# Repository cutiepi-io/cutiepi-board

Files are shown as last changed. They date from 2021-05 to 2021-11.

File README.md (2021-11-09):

# CutiePi board V2.3

This repository provides a custom carrier board designed for the open source CutiePi tablet project, to make use of the Raspberry Pi Compute Module 4.

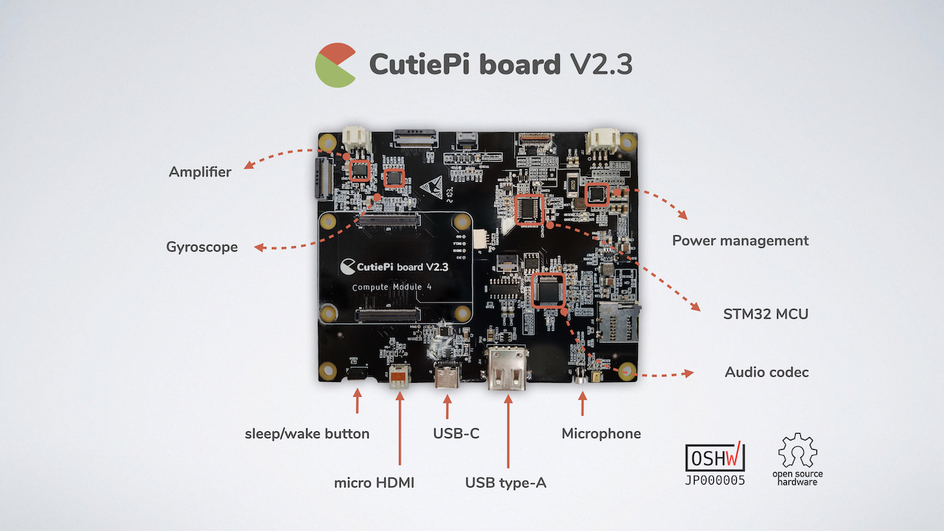
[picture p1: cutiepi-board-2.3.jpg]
 

## Contents

- Cadence OrCAD Schematic [CutiePi_V2.3-20210409.DSN](CutiePi_V2.3-20210409.DSN)
- Cadence OrCAD/Allegro PCB file [CutiePi_V2_3.brd](CutiePi_V2_3_TapeOut/CutiePi_V2_3_PCB/CutiePi_V2_3.brd)
- Bill of Materials [CutiePi_V2.3_BOM-20210802.xlsx](CutiePi_V2.3_BOM-20210802.xlsx)
- PDF of schematic [CutiePi_V2.3_schematic-20210414.pdf](CutiePi_V2.3_schematic-20210414.pdf)

## Copyright and License
Copyright (c) 2021 Zhang "Iron Pillar" Hogan. All rights reserved.

Part of CutiePi board's design is based on Pi Foundation's 
[Compute Module 4 IO Board](https://github.com/raspberrypi/documentation/blob/master/hardware/computemodule/designfiles.md), and we are releasing it under the same [modified BSD license](LICENSE.txt). 

All documentation is licensed under a Creative Commons BY-SA 4.0 international license.

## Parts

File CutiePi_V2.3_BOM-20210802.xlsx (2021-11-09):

No. | Qt | Ref | Value | Package | 备注
1 | 5 | C2,C20,C2484,C2487,C2505 | 47uF/6.3V | C1206
2 | 17 | C17,C383,C384,C385,C2477,C2492,C2493,C2495,C2502,C2503,C2509,C2511,C2512,C2521,C2524,C2525,C2526 | 100nF | C0402
3 | 8 | C24,C86,C2478,C2481,C2501,C2504,C2513,C2520 | 4.7uF/16V | C0603
4 | 4 | C68,C73,C80,C81 | 0.1uF/50V | C0603
5 | 1 | C69 | 1.0uF/25V | C0805
6 | 2 | C74,C78 | 0.22uF/50V | C0805
7 | 2 | C76,C85 | 4.7uF/50V | C1210
8 | 1 | C82 | 1000pF/50V | C0603
9 | 1 | C87 | 0.39uF/16V | C0603
10 | 1 | C386 | 2.2nF | C0402
11 | 4 | C2474,C2480,C2514,C2515 | 1uF/10V | C0402
12 | 2 | C2475,C2476 | 12pF | C0402
13 | 2 | C2479,C2523 | 10nF | C0402
14 | 2 | C2483,C2508 | 2.2uF | C0402
15 | 8 | C2485,C2486,C2488,C2489,C2490,C2491,C2496,C2497 | 10uF/16V | C0805
16 | 3 | C2507,C2516,C2518 | 10uF/16V | C0603
17 | 4 | C2510,C2517,C2519,C2522 | 47pF | C0603
18 | 2 | D1,D23 | RED | LED0603
19 | 1 | D10 | SS14-M3/61T | DO-214AC
20 | 4 | D11,D12,D13,D14 | ESDLIN1524BJ | SOD323
21 | 2 | D17,D18 | BAT54HT1 | DIO-SOD323
22 | 4 | D19,D20,D21,D22 | GREEN | LED0603
23 | 7 | FB2,FB7,FB8,FB9,FB10,FB12,FB13 | BLM18PG121SH1 | SL0603
24 | 1 | F1 | 6V/2A | 1206
25 | 1 | F2 | 6V/0.5A | 1206
26 | 1 | J2 | Type C-16 | TYPEC_6446_116FH1301 | https://detail.tmall.com/item.htm?id=609627153021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
27 | 1 | J7 | SH1.0-4 | SH1_0_4 | https://detail.tmall.com/item.htm?id=548124065090&rn=de18d88c60677f1377dbfd09a6918efa&abbucket=17
28 | 1 | J9 | SH1.0-2 | SH1_0_2 | https://detail.tmall.com/item.htm?pos=2&acm=03054.1003.1.2768562&id=548071500587&skuId=3324081389692
29 | 2 | J11,J26 | FH52-22S-0.5SH | CONFPC22_05MM_FH52_a
30 | 1 | J13 | 467651001 | Micro_HDMI
31 | 1 | J14 | USB-A | USB_AM
32 | 1 | J16 | 473521001_sd | MOLEX_473521001
33 | 2 | J17,J28 | FH52-6S-0.5SH | confpc6_05mm_FH52
34 | 1 | J21 | FH26W-31S-0.3SHW | confpc31_03mm_FH26w
35 | 1 | J23 | PH2.0-3_NC | PH2_0_3
36 | 2 | J24,J25 | DF40C-100DS-0.4V | FCI_10033853_CM
37 | 1 | J27 | MIC4.5 | MIC_4_5 | https://detail.tmall.com/item.htm?id=524833449267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
38 | 1 | L5 | 10uH/20% | SHC0402
39 | 1 | L634 | 1.5uF | SHC0402
40 | 5 | Q3,Q4,Q5,Q6,Q7 | DMG1012T | SOT50P160X90-3N
41 | 8 | R3,R3060,R3087,R3095,R3097,R3100,R3178,R3179 | 2.49K | R0402
42 | 11 | R15,R87,R118,R3040,R3061,R3101,R3167,R3173,R3176,R3180,R3182 | 10K_NC | R0402
43 | 9 | R16,R17,R114,R115,R124,R3165,R3166,R3168,R3169 | 4.7K | R0402
44 | 33 | R18,R117,R272,R368,R371,R3039,R3043,R3044,R3054,R3057,R3059,R3062,R3066,R3088,R3094,R3096,R3099,R3102,R3104,R3105,R3108,R3132,R3145,R3149,R3160,R3163,R3164,R3177,R3181,R3183,R3186,R3189,R3196 | 10K | R0402
45 | 25 | R42,R43,R88,R89,R120,R121,R127,R370,R373,R3041,R3042,R3058,R3098,R3153,R3156,R3157,R3158,R3172,R3174,R3175,R3193,R3194,R3195,R3197,R3200 | 0 | R0402
46 | 4 | R90,R91,R3184,R3188 | 3.3 | R0603
47 | 9 | R122,R123,R3154,R3155,R3161,R3162,R3198,R3199,R3201 | 0_NC | R0402
48 | 2 | R125,R126 | 20K | R0402
49 | 2 | R3049,R3103 | 30.1K | R0402
50 | 3 | R3051,R3053,R3065 | 52.3K | R0402
51 | 4 | R3052,R3064,R3091,R3093 | 15K | R0402
52 | 1 | R3063 | 3.3_NC | R0603
53 | 1 | R3086 | 31.6K | R0402
54 | 1 | R3089 | 20m/1W | R2512
55 | 4 | R3090,R3133,R3134 | 5.1K | R0402
56 | 1 | R3106 | 82.5K | R0402
57 | 1 | R3107 | 39.2K | R0402
58 | 1 | R3137 | 36.5K | R0402
59 | 6 | R3138,R3139,R3140,R3141,R3142,R3143 | 22 | R0402
60 | 3 | R3185,R3187,R3190 | 2.2K | R0402
61 | 2 | R3191,R3192 | 8.2K | R0402
62 | 1 | SW2 | TC-0143 | Button
63 | 39 | TP28,TP29,TP30,TP33,TP41,TP43,TP44,TP45,TP46,TP47,TP52,TP57,TP58,TP59,TP60,TP61,TP62,TP63,TP64,TP65,TP77,TP78,TP79,TP80,TP81,TP83,TP84,TP89,TP90,TP91,TP92,TP93,TP94,TP95,TP97,TP98,TP99,TP100,TP101 | TEST POINT | testpoint_39mil
64 | 1 | U3 | HS100B | QFN48_05MM_0707MMLTS
65 | 2 | U5,U601 | IP4234CZ6 | TSOP6
66 | 1 | U6 | TPS61165DBV | SOT23_6B
67 | 1 | U12 | LM4871MX | SOIC8_1D27MM
68 | 1 | U18 | STM32F030F4P6 | TSSOP20_0D65MM
69 | 1 | U57 | MPU6050 | QFN24_05MM_0404MML
70 | 1 | U60 | TPS73601DBVR | SOT23_5
71 | 1 | U501 | SPU0410HR5H_NC | lga5_cav_4p1x3p1mm
72 | 1 | U580 | AT93C46 | SOIC8
73 | 1 | U597 | MP2636GR | QFN-30
74 | 1 | U600 | HS8836A | SOP16_1P27_HS8836A
75 | 1 | U602 | FSUSB42MUX | sop10_20_120a
76 | 1 | Y2 | 25M_NC | XTAL_3225_25M_A
77 | 1 | R3092 | 3K | R0402
78 | 1 | Cxxx | 220uF/10V | 引脚，手工焊接！
79 | 1 |  |  | U602 1脚跟2脚短接
 |  |  |  | 注意PCB板厚1.2mm！！！

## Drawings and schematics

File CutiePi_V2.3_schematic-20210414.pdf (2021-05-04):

DISPLAY | CAMMERA 1 | CAMMERA 0

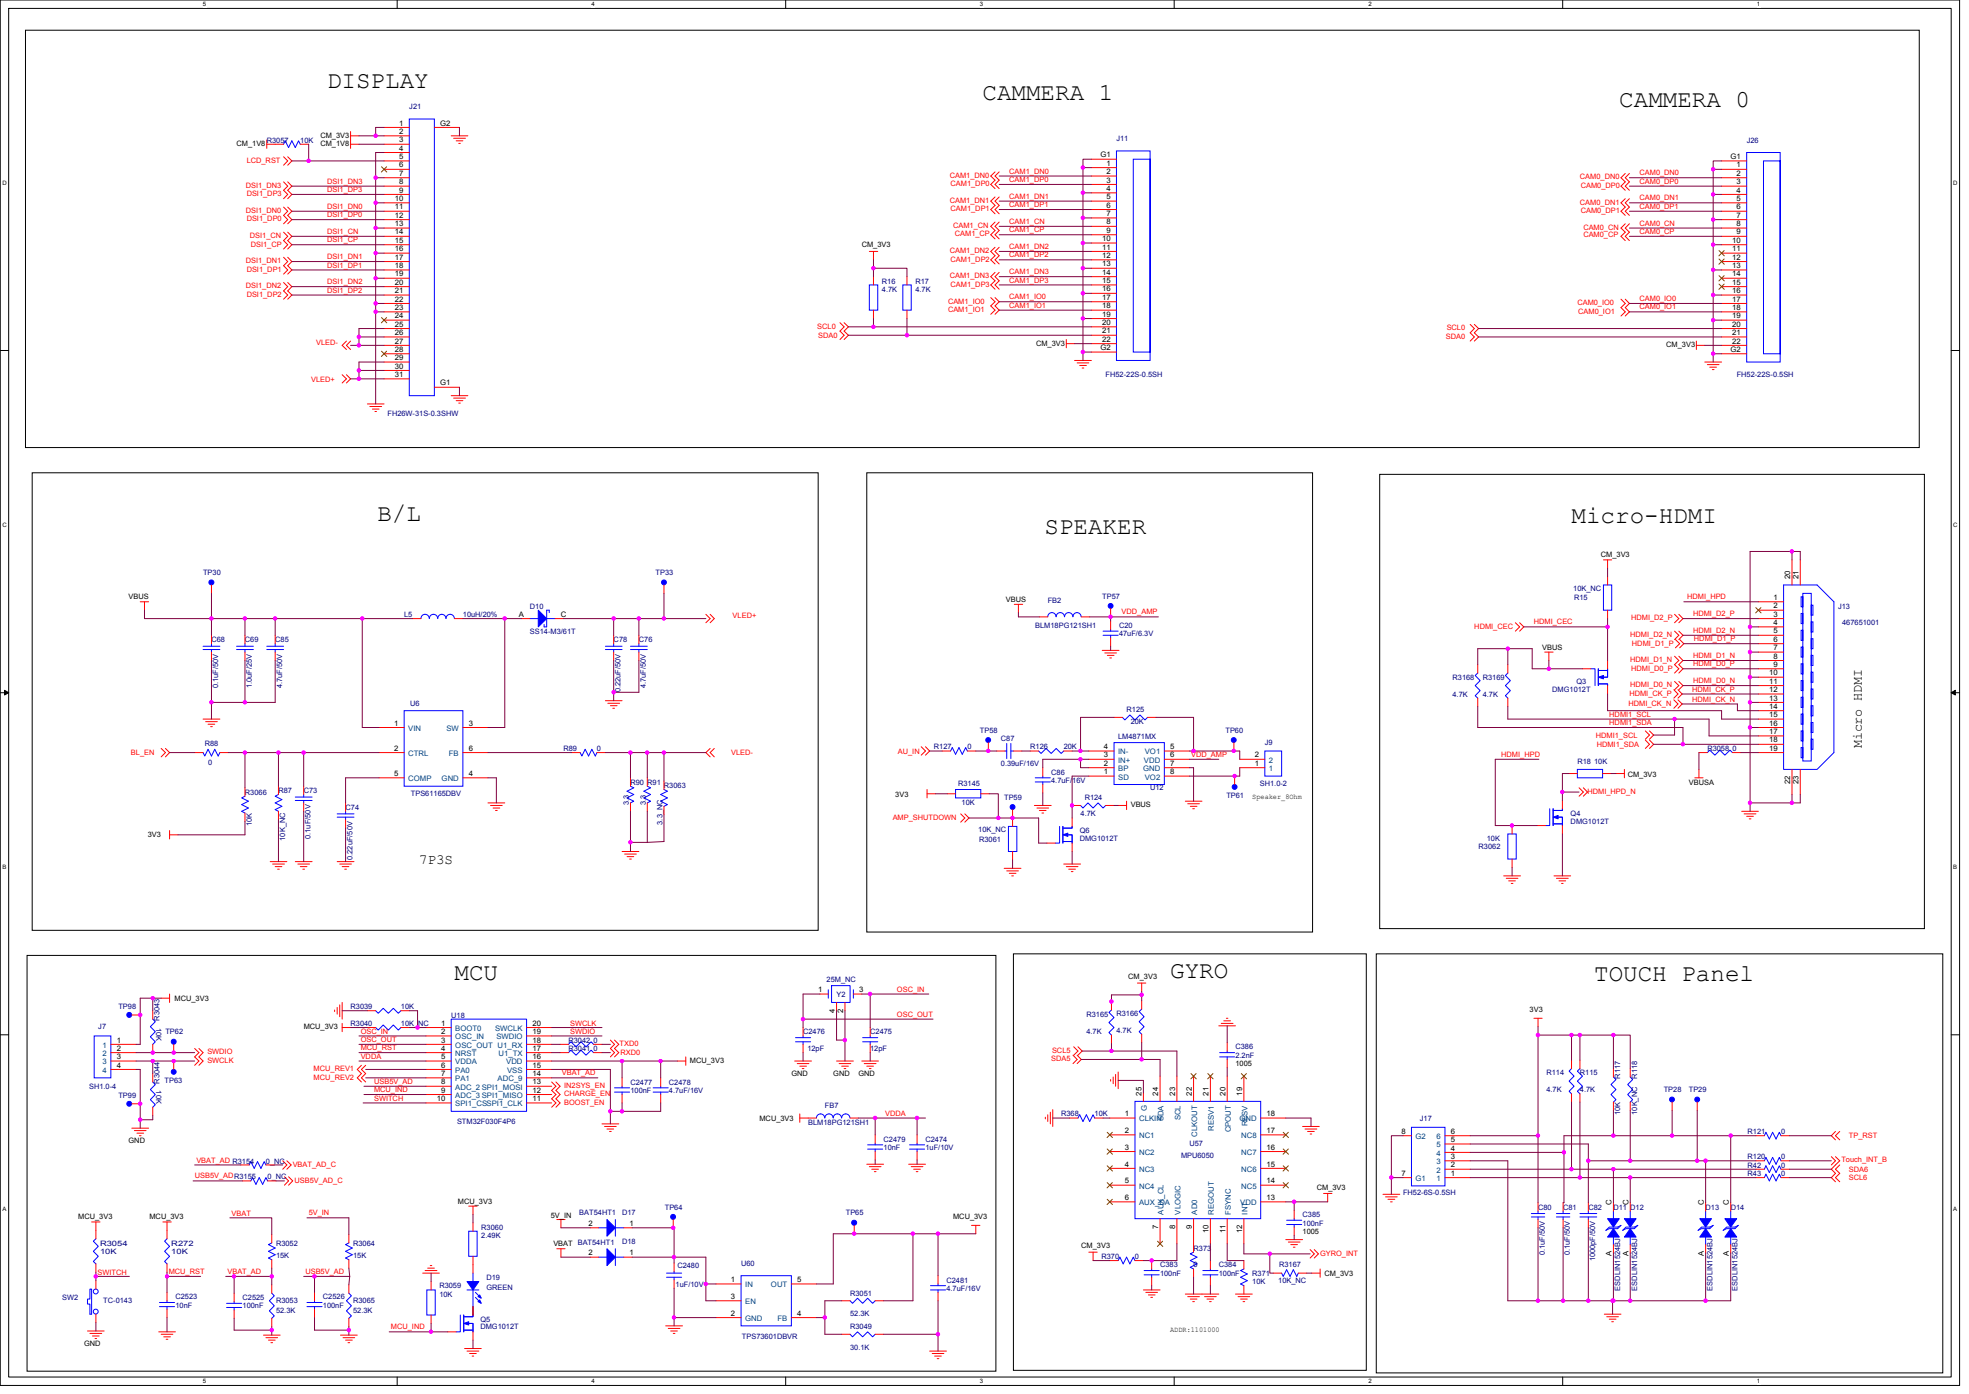
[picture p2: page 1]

# USB A

# BATTERY

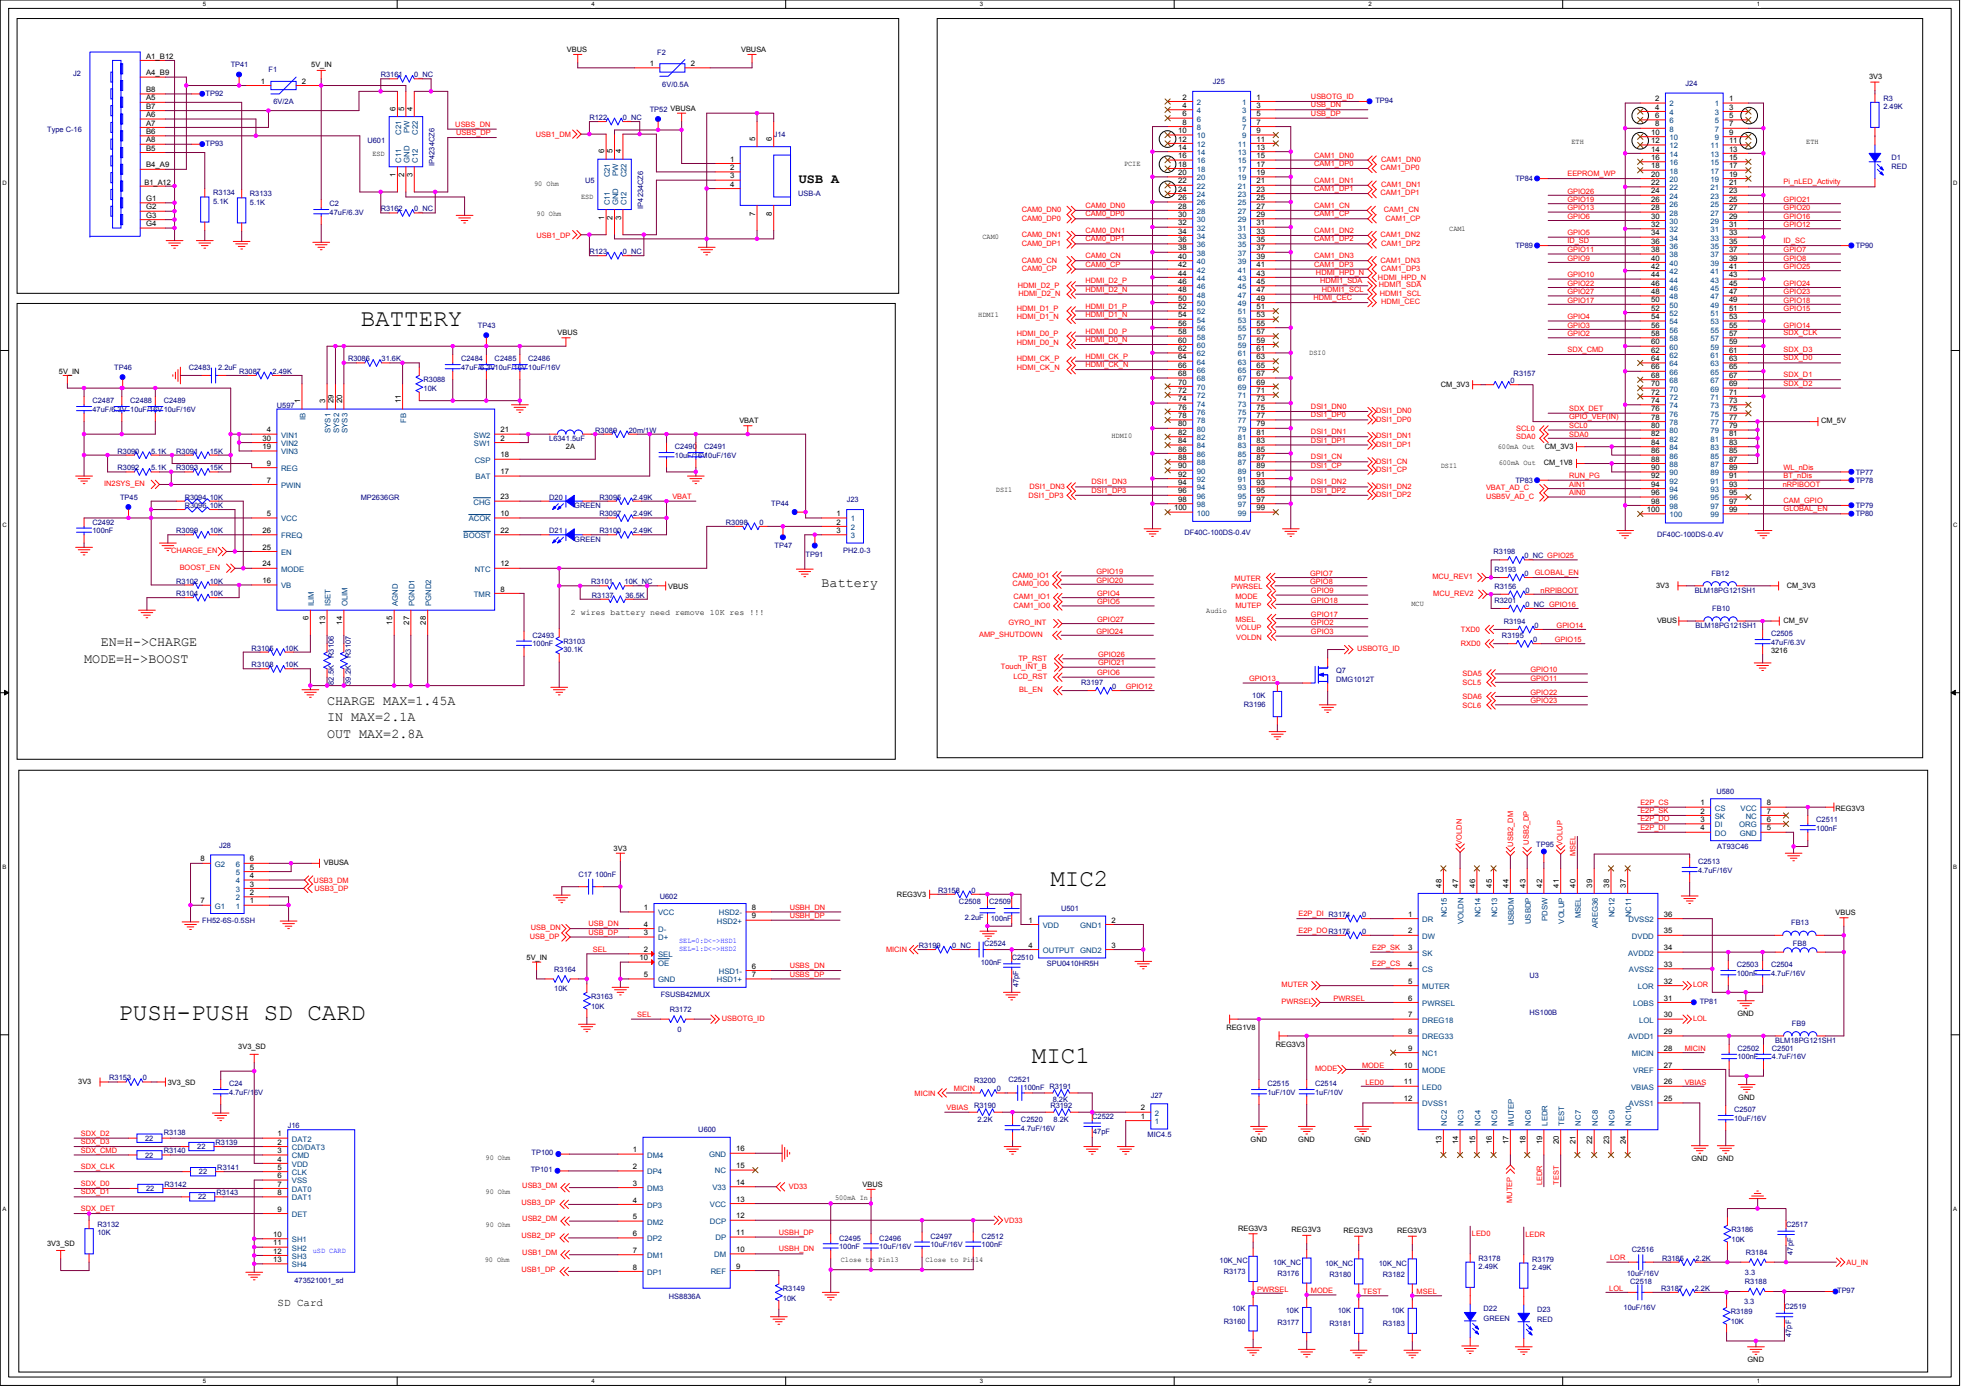
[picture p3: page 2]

2 wires battery need remove 10K res !!!

PUSH-PUSH SD CARD

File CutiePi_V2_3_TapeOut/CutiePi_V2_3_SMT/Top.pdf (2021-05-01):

# ART FILM - ADT

R127C386

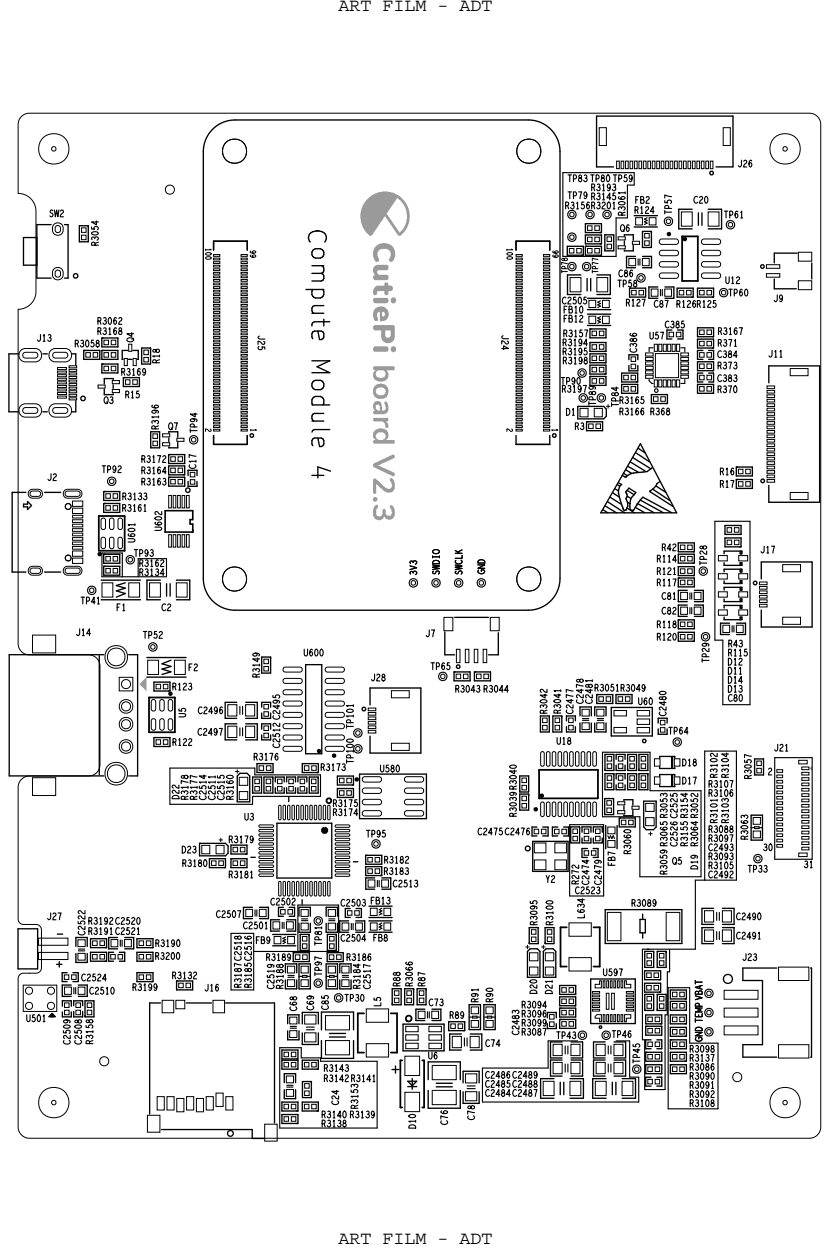
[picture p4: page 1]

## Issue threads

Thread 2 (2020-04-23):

GYRO and Camera on I2C-1

lutzh86, 2020-04-23:
So while playing with camera, the gyro is not accessible?

penk, 2020-04-24:
Hi @lutzh86, thanks for reaching out. We will address this issue in next revision by using DSI + Camera in one bus, and Gyro in the other.

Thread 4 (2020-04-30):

FPGA coprocesor

0xtrzy, 2020-04-30:
I like Fomu or other good project fpga.
Is possible add in second version small fpga processor directly on board? Or in version 1 more STM processor for kernel.

Many programs need small power. Many emulators working on fpga and RISC-V, DOS, Commodore

penk, 2020-05-03:
@0xtrzy that's a really cool idea, I'll mark as future ideas.

sp00ck, 2022-03-04:
https://1bitsquared.com/products/orangecrab this is very cool,
power lipo on board etc.

**As in your project not enough USB C ports, I would need at least 3 USB C ports and two USB A host**

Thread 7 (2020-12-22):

CM4 version HDMI interface differs from CM4IO board

dp111, 2020-12-22:
On the schematics the HDMI interface looks like the CM3+ HDMI interface. The CM4 has a simplified interface, see the CM4IO board. You no longer need the ESD device as that is built into the CM4 also you no longer need the hotplug is inversion.

penk, 2020-12-22:
Thanks! We will address this change in the next revision.

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

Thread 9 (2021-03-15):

Switch to KiCAD or FOSS alternative

bggardner, 2021-03-15:
I love this project, but it's a stretch to claim it's open-source if closed-source software is required to modify the design files.  Please consider switching to KiCAD, etc., or at least post a KiCAD-friendly version of the source.  Thanks!

boelle, 2022-01-21:
i agree and said the same here: https://github.com/cutiepi-io/cutiepi-board/issues/12

penkchen, 2022-01-22:
@bggardner @boelle Thank you for the issue and comment, I understand your point.

When we started the design of current version, we needed a lot of external help to mass produce it.
From circuit layout, routing, CAD modelling, and PCBA prototyping. All these contractors or companies we worked with were not using KiCAD, as you may have already known, proprietary software is still the de facto in this industry.

However we learned a lot during the process, and hopefully in the future version of the design, we can introduce FOSS format into some of the process, just like The Raspberry Pi did with CMIO v3 to CMIO v4.

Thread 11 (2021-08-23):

LCD and Battery models

arturo182, 2021-08-23:
I might've missed it somewhere, but I think there is no info on the LCD and the battery part numbers and/or links?

penk, 2021-08-24:
Hi @arturo182 , (btw, big fan of your keyboard featherwing works :-)

We supported/tested two MIPI DSI displays:
1. AML080WXBI3103S (https://www.amelin.com.cn/h-pd-104.html)
2. TXW800018S0-LSS (http://www.txwlcd.cn/en/h-pd-437.html#fai_14_top&pfc=&_pp=0_35)

The former one uses a `JD9366` controller, and the later one uses `ILI9881C`. You can find the out-of-tree drivers here: https://github.com/cutiepi-io/cutiepi-drivers#mipi-display

As for battery, any 3.7V li-po battery goes. We found a 5259109 one that best fits the case. Unfortunately the vendor does not sell sample on aliexpress/taobao.

Closed 2021-08-24.

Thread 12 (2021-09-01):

Export the brd and schematic files to be compatible with eagle or kicad

rahmanshaber, 2021-09-01:
Most of us don't have Cadence software, if possible export the files to a universal file so everyone can make use of it. also if possible a separate library file that includes all the parts used in the design.
thanks.

boelle, 2022-01-21:
same here... i wanted to see how much i could remove and if it would make sense

ie i dont need the camera or the 2 mic's, nor the ports other than charging

pdf's are ok'ish, but yeah kicad (free) would have been nice

penk, 2022-01-22:
Close as duplicate to issue #9, please see my comment there. Thank you!

Closed 2022-01-22.

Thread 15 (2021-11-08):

USB C changing cannot be pulled out.

usstlf, 2021-11-08:
The MP2636GR can not full fill requirement of CM4.
CM4 works between 4.75 to 5.25 V.
If the USB C is plugged in then pulled out.
The MP2636GR can first start the boost of battery when the voltage dropped to battery voltage + 300mv.
This will cause the CM4 shut down.
we found a temporary solution for this, change the R3092 to 3k, it will solve the problem.
But the resistor must be very precision. above 3.3k or below 2.7k will not solve this problem.
We afraid that the tk of resistor will also impact the reliability of the pad.
But we didn't have further test.

penk, 2021-11-09:
Hi @usstlf, thank you for the report, we solved this issue by 1) changing R3092 to 3k, and 2) adding one 10V/220uF capacitor at C2505 in parallel. The latest BOM should reflects that change.

Closed 2021-11-09.

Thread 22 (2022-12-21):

display LCD_RST schematic vs dt-overlay

Darmur, 2022-12-21:
In the latest schematic (v2.3) the !RST pin of the display LCD_RST is connected to GPIO6 of the CM4.

looking at the dt-overlay source cutiepi-panel-overlay.dts, I could not find where the GPIO6 as !RST is declared.

the only part where I can see something related to the display rst is this:

`reset-gpios = <&gpio 20 0>;`

but it looks like &gpio is the numner 12, used for backlight control

```
fragment@1 {
        target = <&gpio>;
        __overlay__ {
            pwm_pins: pwm_pins {
                brcm,pins = <12>;
                brcm,function = <4>; // ALT0
            };
        };
    };
```

could you please clarify?

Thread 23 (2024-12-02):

Adding MSATA or NVMe support or a 10-11" model?

Tokobotenkai, 2024-12-02:
Hi, just wanted to say amazing work on this.

Not sure how to submit a feature request.

I was wondering, I heard the CM5 is a drop in replacement for the CM4 boards, would something like an MSATA or NVMe slot be feasible rather than just the SD card.

Also, I was wondering have you considered a 10-11" screen model for larger screen real estate?

Thank you.

uazzamerican, 2025-09-24:
Hello, I am struggling in contacting you so sorry if I am using this inappropriately.
May I ask you the very bios dump of your ASUS Z97 Pro Wi-Fi/ac motherboard please?

uazzamerican, 2025-09-24:
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

Hello, I am struggling in contacting you so sorry if I am using this inappropriately.
May I ask you the very bios dump of your ASUS Z97 Pro Wi-Fi/ac motherboard please?

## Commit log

2019-09-16 Added V1.1 design files
    [BOM-20190325.xlsx, CUTIEPI.brd, CUTIEPI_20190322.DSN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]
2019-09-17 Add V1.1 schematics
2019-09-17 Updated design file
    [CutiePi V1.1_20190917.DSN]
2019-09-25 File updated
    [CutiePi V1.1 Change List.xlsx, CutiePi V1.1_20190918.DSN]
2019-10-24 Upload gerber files
    [CutiePi_V1.1_PCB制作说明.xls, CutiePi_V1_1.brd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]
2019-10-24 Better naming
    [CutiePi_V1.1-20191018.DSN, CutiePi_V1.1_BOM-20191018.xlsx, CutiePi_V1.1_changes.xlsx]
2020-03-10 Update design files to v1.2
    [CutiePi_V1.1-20191018.DSN, CutiePi_V1.1_BOM-20191108.xlsx, CutiePi_V1.1_PCB制作说明.xls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]
2020-11-26 Upgrade for CM4
    [CutiePi_V1.2-20200310.DSN, CutiePi_V1.2_BOM-20200310.xlsx, CutiePi_V1.2_PCB制作说明.xls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]
2020-12-02 Add BOM and gerber files
    [CutiePi_V2.0_BOM-20201119.xlsx, CutiePi_V2_0.brd, CutiePi_V2_0_1126.brd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]
2021-05-01 Update to v2.3 design
    [CutiePi_V2.0-20201123.DSN, CutiePi_V2.0_BOM-20201119.xlsx, CutiePi_V2.3-20210409.DSN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]
2021-11-09 Update the production BOM
    [CutiePi_V2.3_BOM-20210414.xlsx, CutiePi_V2.3_BOM-20210802.xlsx]
